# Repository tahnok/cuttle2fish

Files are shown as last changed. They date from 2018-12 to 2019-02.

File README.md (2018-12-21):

# Cuttle2Fish

Something you know (password) and something you have (cuttlefish shaped U2F token)

Based on the STM32F103

## Software

Intended to be based on https://github.com/gl-sergei/u2f-token

## Design Notes

https://github.com/tahnok/wiki/wiki/cuttle2fish

## Pictures

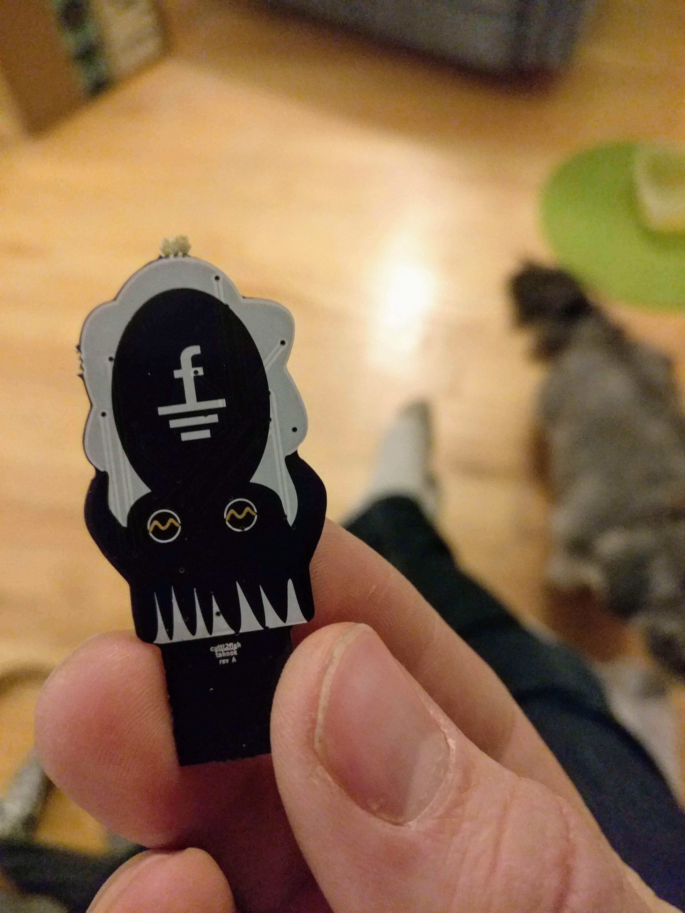
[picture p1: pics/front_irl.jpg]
front IRL


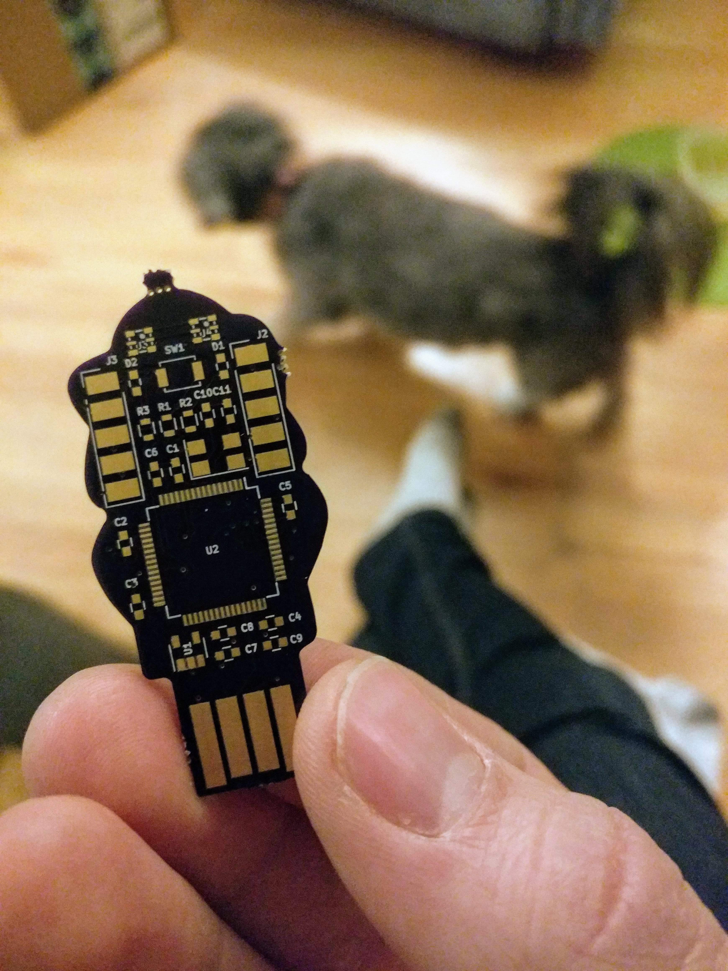
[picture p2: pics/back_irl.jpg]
back IRL


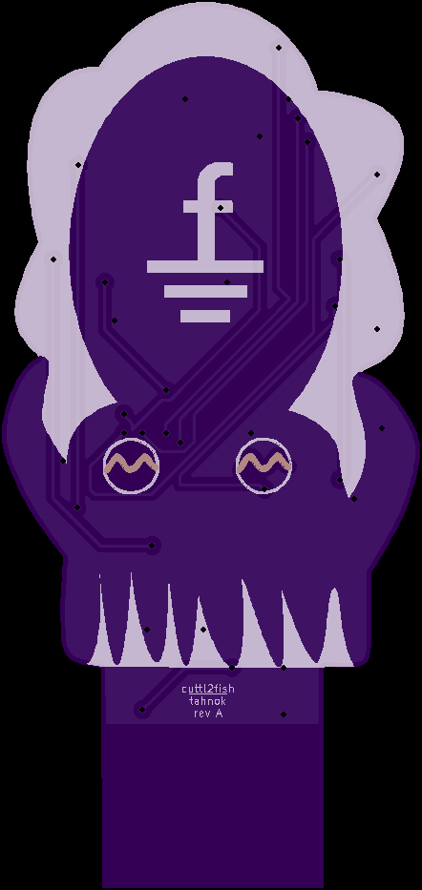
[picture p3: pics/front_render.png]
front render


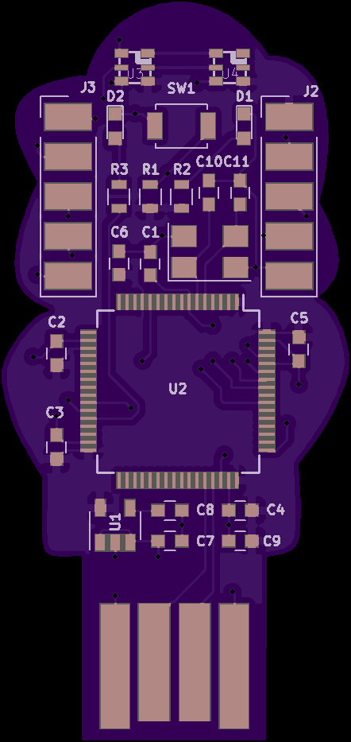
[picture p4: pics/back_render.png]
back render


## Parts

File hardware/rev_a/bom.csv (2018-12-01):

Reference | Quantity | Value | Footprint
C11 C10 | 2 | 4.7pF | SMD 0603 | https://www.digikey.ca/product-detail/en/CL10C4R7BB8NNNC/1276-1792-1-ND/3889878/?itemSeq=278517564
C6 C5 C4 C3 C2 C1 | 6 | 100nF | SMD 0603 | https://www.digikey.ca/product-detail/en/CC0603KRX7R7BB104/311-1088-1-ND/302998/?itemSeq=278517701
C8 | 1 | 10nF | SMD 0603 | https://www.digikey.ca/product-detail/en/CL10B103KB8NCNC/1276-1921-1-ND/3890007/?itemSeq=278517735
C9 C7 | 2 | 4.7uF | SMD 0603 | https://www.digikey.ca/product-detail/en/CL10A475MP5LNNC/1276-6684-1-ND/5961543/?itemSeq=278517785
D1 D2 | 2 | LED | SMD 0603 | https://www.digikey.ca/product-detail/en/SML-D12U1WT86/SML-D12U1WT86CT-ND/5843858/?itemSeq=278517839
R1 | 1 | 10K | SMD 0603 | https://www.digikey.ca/product-detail/en/ESR03EZPF1002/RHM10KADCT-ND/1983753/?itemSeq=278517879
R2 R3 | 2 | 330 | SMD 0603 | https://www.digikey.ca/product-detail/en/ESR03EZPJ331/RHM330DCT-ND/1762933/?itemSeq=278517891
SW1 | 1 | B3U-1000P | B3U-1000P | https://www.digikey.ca/product-detail/en/B3U-1000P/SW1020CT-ND/1534357/?itemSeq=278517290
U1 | 1 | LP2985-3.3 | SMD SOT-23-5 | https://www.digikey.ca/product-detail/en/LP2985-33DBVR/296-18476-1-ND/809911/?itemSeq=278517279
U2 | 1 | STM32F103R(8-B)Tx | LQFP 64 10x10mm Pitch0.5mm | https://www.digikey.ca/product-detail/en/STM32F103RBT7/497-11526-ND/2035337/?itemSeq=278517258
U3 U4 | 2 | APA102-2020 | APA102-2020 | https://www.aliexpress.com/item/-/32856952551.html
Y1 | 1 | 10pF | SMD 5032 | https://www.digikey.ca/product-detail/en/ECS-80-10-30B-CWN-TR/XC2708CT-ND/8023643/?itemSeq=278517568

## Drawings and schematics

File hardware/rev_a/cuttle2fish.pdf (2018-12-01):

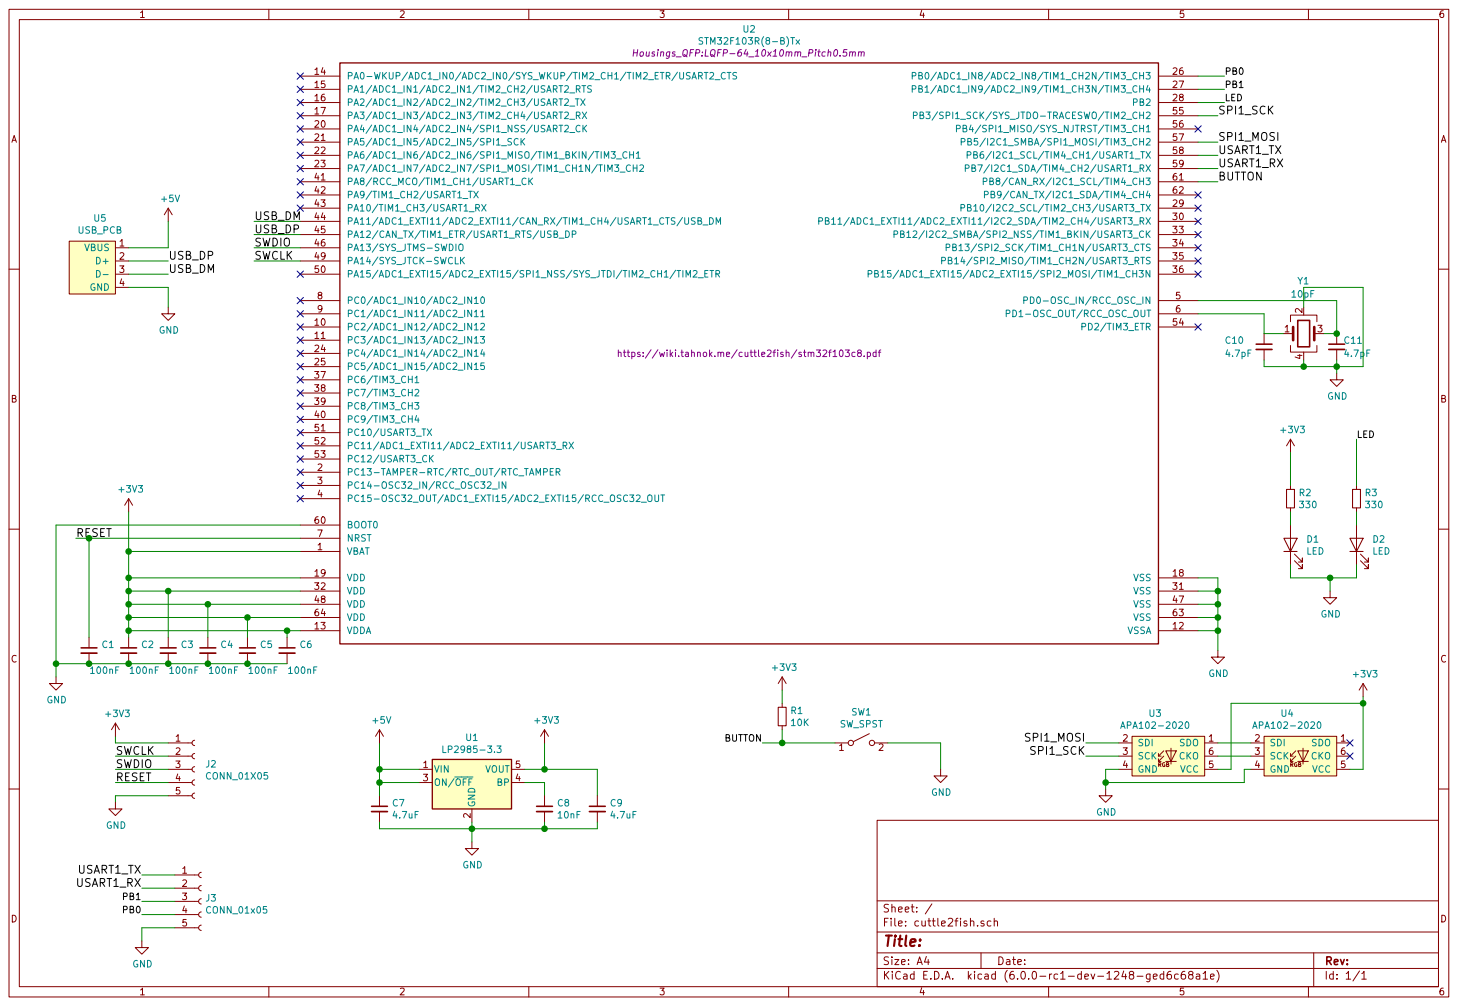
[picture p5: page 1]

2 ON/OFF 3 BP 4 VOUT 5 U1

Id: 1/1 Title: File: cuttle2fish.sch Sheet: /

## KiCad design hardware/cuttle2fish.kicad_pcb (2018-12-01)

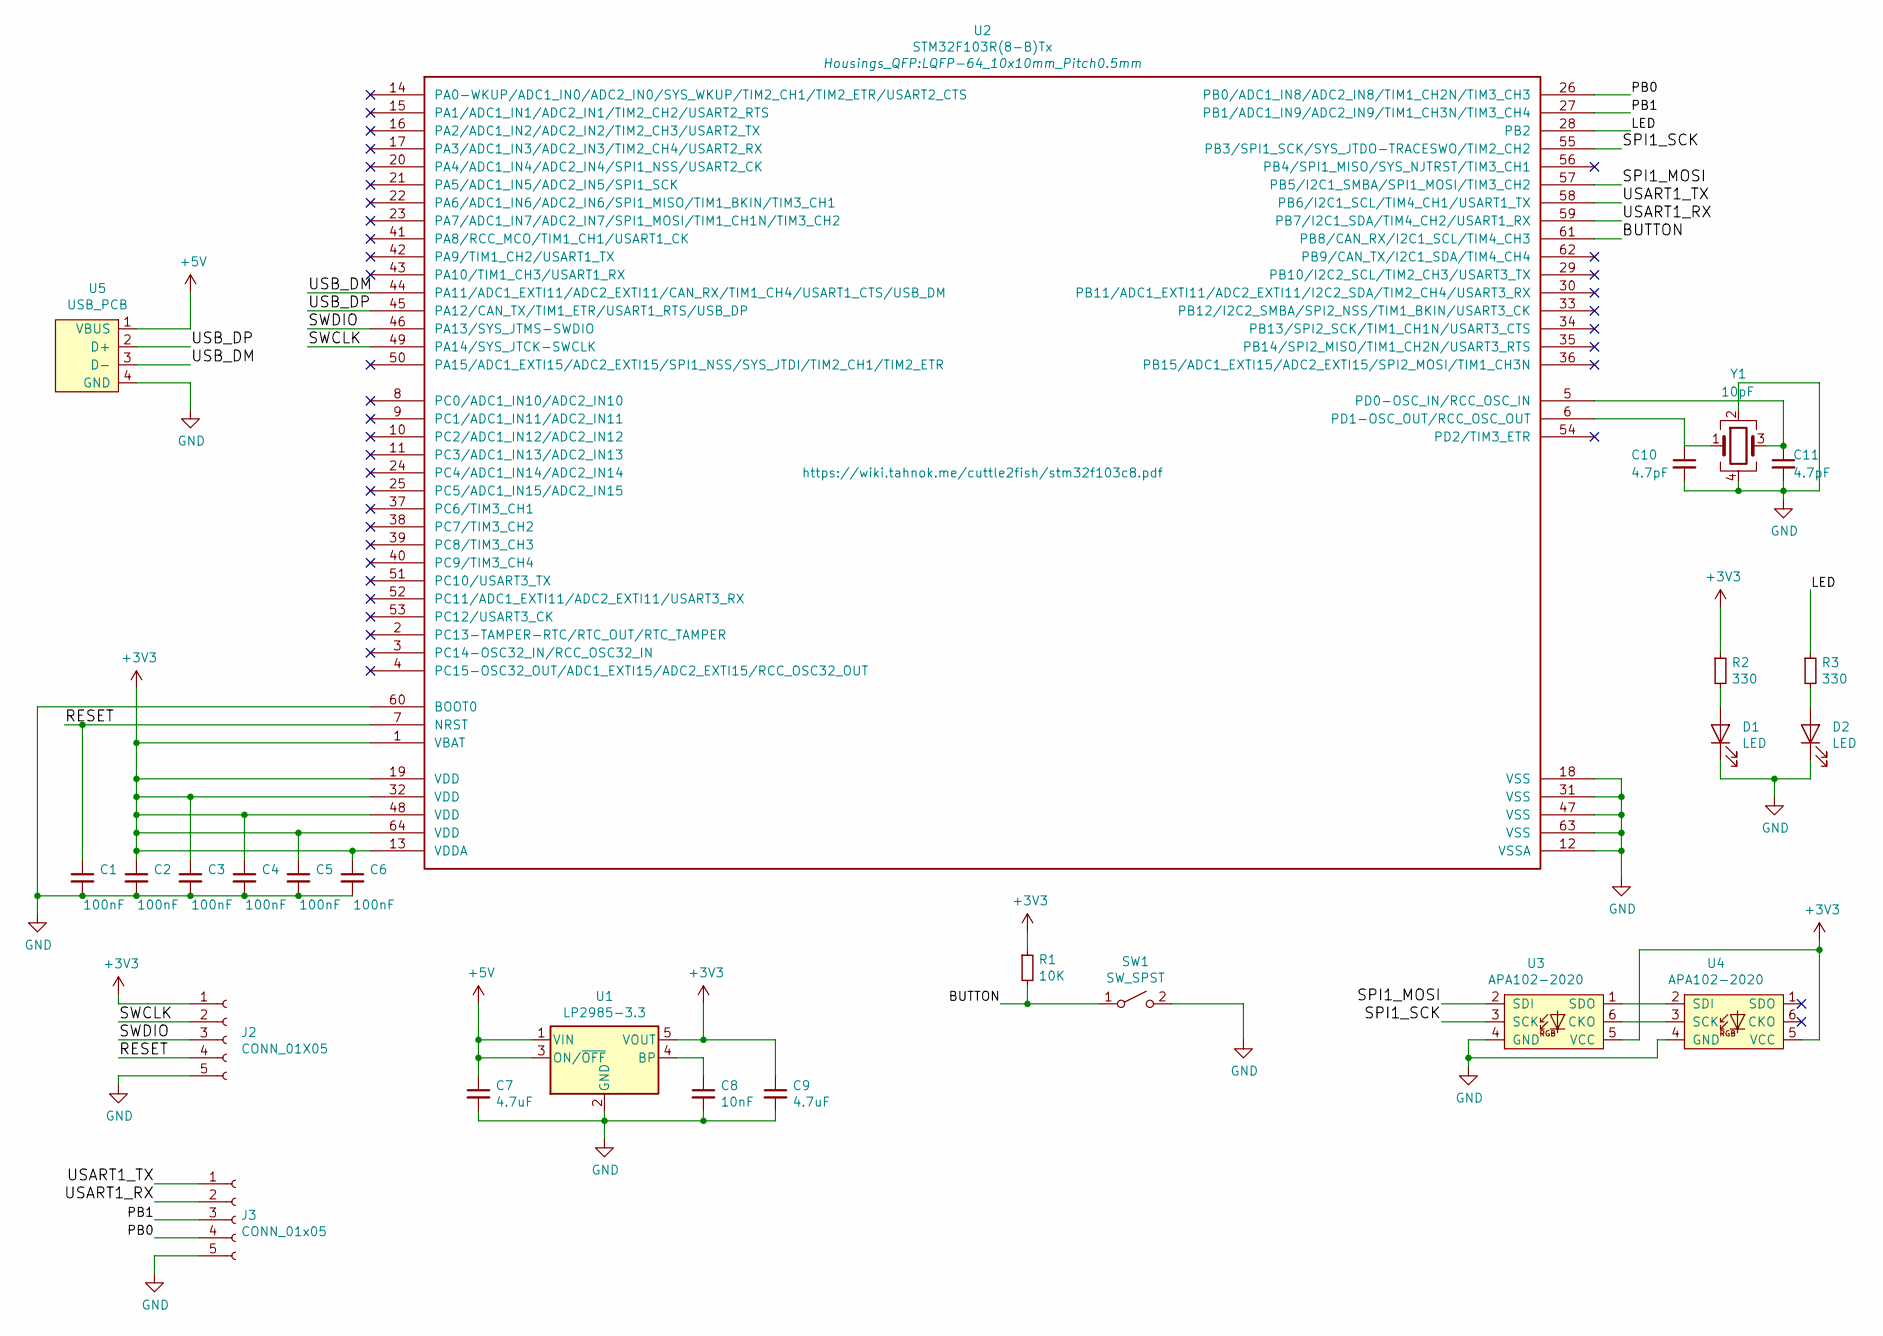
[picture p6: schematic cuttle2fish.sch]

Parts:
C1, C2, C3, C4, C5, C6: 100nF; C_0603
C7, C9: 4.7uF; C_0603
C8: 10nF; C_0603
C10, C11: 4.7pF; C_0603
D1, D2: LED; LED_0603
J2: CONN_01X05; Pin_Header_Straight_1x05_Pitch2.54mm
J3: CONN_01x05; Pin_Header_Straight_1x05_Pitch2.54mm
R1: 10K; R_0603
R2, R3: 330; R_0603
SW1: SW_SPST; SW_SPST_B3U-1000P
U1: LP2985-3.3; SOT-23-5
U2: STM32F103R(8-B)Tx; LQFP-64_10x10mm_Pitch0.5mm
U3, U4: APA102-2020
U5: USB_PCB; usb-PCB
Y1: 10pF; Crystal_SMD_5032-4pin_5.0x3.2mm

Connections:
+3V3: C2.1, C3.1, C4.1, C5.1, C6.1, C9.1, J2.1, R1.1, R2.1, U1.5 (VOUT), U2.1 (VBAT), U2.13 (VDDA), U2.19 (VDD), U2.32 (VDD), U2.48 (VDD), U2.64 (VDD), U3.5 (VCC), U4.5 (VCC)
+5V: C7.1, U1.1 (VIN), U1.3 (ON/~OFF~), U5.1 (VBUS)
/BUTTON: R1.2, SW1.1 (A), U2.61 (PB8/CAN_RX/I2C1_SCL/TIM4_CH3)
/LED: R3.1, U2.28 (PB2)
/PB0: J3.4, U2.26 (PB0/ADC1_IN8/ADC2_IN8/TIM1_CH2N/TIM3_CH3)
/PB1: J3.3, U2.27 (PB1/ADC1_IN9/ADC2_IN9/TIM1_CH3N/TIM3_CH4)
/RESET: C1.1, J2.4, U2.7 (NRST)
/SPI1_MOSI: U2.57 (PB5/I2C1_SMBA/SPI1_MOSI/TIM3_CH2), U3.2 (SDI)
/SPI1_SCK: U2.55 (PB3/SPI1_SCK/SYS_JTDO-TRACESWO/TIM2_CH2), U3.3 (SCK)
/SWCLK: J2.2, U2.49 (PA14/SYS_JTCK-SWCLK)
/SWDIO: J2.3, U2.46 (PA13/SYS_JTMS-SWDIO)
/USART1_RX: J3.2, U2.59 (PB7/I2C1_SDA/TIM4_CH2/USART1_RX)
/USART1_TX: J3.1, U2.58 (PB6/I2C1_SCL/TIM4_CH1/USART1_TX)
/USB_DM: U2.44 (PA11/ADC1_EXTI11/ADC2_EXTI11/CAN_RX/TIM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), U5.3 (D-)
/USB_DP: U2.45 (PA12/CAN_TX/TIM1_ETR/USART1_RTS/USB_DP), U5.2 (D+)
GND: C1.2, C2.2, C3.2, C4.2, C5.2, C6.2, C7.2, C8.2, C9.2, C10.2, C11.2, D1.1 (K), D2.1 (K), J2.5, J3.5, SW1.2 (B), U1.2 (GND), U2.12 (VSSA), U2.18 (VSS), U2.31 (VSS), U2.47 (VSS), U2.60 (BOOT0), U2.63 (VSS), U3.4 (GND), U4.4 (GND), U5.4 (GND), Y1.2, Y1.4
unnamed: C8.1, U1.4 (BP)
unnamed: C10.1, U2.6 (PD1-OSC_OUT/RCC_OSC_OUT), Y1.1
unnamed: C11.1, U2.5 (PD0-OSC_IN/RCC_OSC_IN), Y1.3
unnamed: D1.2 (A), R2.2
unnamed: D2.2 (A), R3.2
unnamed: U3.1 (SDO), U4.2 (SDI)
unnamed: U3.6 (CKO), U4.3 (SCK)

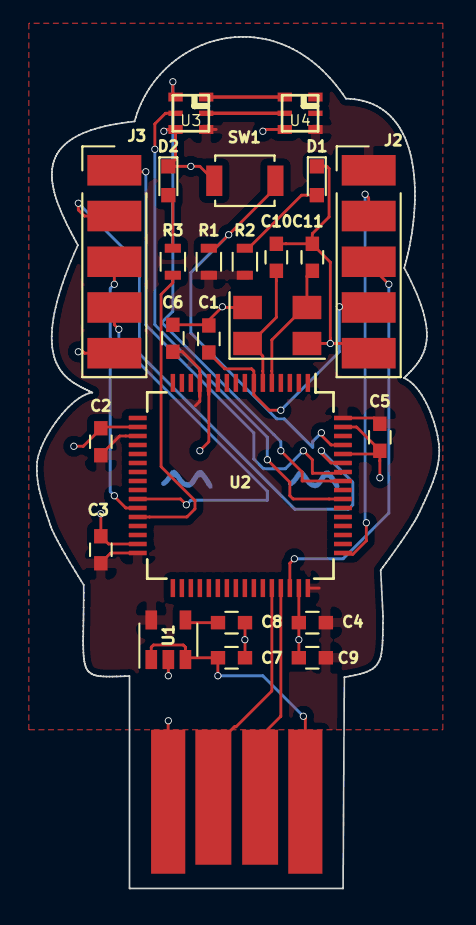
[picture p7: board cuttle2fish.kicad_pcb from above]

Board: 2 copper layers, 22.4 x 47.3 mm, 26 parts (1 on the bottom side), 23 nets.

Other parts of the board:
svg2mod: G***; outline

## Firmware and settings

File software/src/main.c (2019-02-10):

/*
 * This file is part of the libopencm3 project.
 *
 * Copyright (C) 2009 Uwe Hermann <uwe@hermann-uwe.de>
 *
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
 * You should have received a copy of the GNU Lesser General Public License
 * along with this library.  If not, see <http://www.gnu.org/licenses/>.
 */
#include <libopencm3/stm32/rcc.h>
#include <libopencm3/stm32/gpio.h>

static void
gpio_setup(void) {

	/* Enable GPIOC clock. */
	rcc_periph_clock_enable(RCC_GPIOB);

	/* Set GPIO8 (in GPIO port C) to 'output push-pull'. */
	gpio_set_mode(GPIOB,GPIO_MODE_OUTPUT_2_MHZ,
		      GPIO_CNF_OUTPUT_PUSHPULL,GPIO2);
	gpio_set_mode(GPIOB, GPIO_MODE_INPUT, GPIO_CNF_INPUT_FLOAT, GPIO6);
}

int
main(void) {
	int i;

	gpio_setup();

	uint16_t result;

	for (;;) {
		result = gpio_get(GPIOB, GPIO6);
		if(result) {
			gpio_clear(GPIOB,GPIO2);	/* LED on */
		} else {
			gpio_set(GPIOB,GPIO2);		/* LED off */
		}

	}

	return 0;
}

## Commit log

2018-11-11 Add skeleton kicad project
    [cuttle2fish.kicad_pcb, cuttle2fish.sch]
2018-11-20 add first pass at USB and power caps
    [cuttle2fish.sch]
2018-11-24 Update cuttle2fish.sch
    Add labels for pins we want to break out and programming connector
    [cuttle2fish.sch]
2018-11-25 Add APA102, button, PMIC
    [cuttle2fish.sch]
2018-11-25 Rev 1 schematic
    [cuttle2fish.sch]
2018-11-25 Add APA102 footprint from great scott gadgets
    https://github.com/greatscottgadgets/gsg-kicad-lib/blob/master/gsg-modules.pretty/APA102-2020.kicad_mod
    [cuttle2fish.sch]
2018-11-25 Add LEDs and button footprint
    [cuttle2fish.sch]
2018-11-25 Add PCB USB footprint and symbol from USBArmory
    https://github.com/inversepath/usbarmory
    [cuttle2fish.sch]
2018-11-25 rename symbol file from test to symbols
    [cuttle2fish.sch]
2018-11-30 add outline footprint and start routing!
    [cuttle2fish.kicad_pcb, cuttle2fish.sch]
2018-12-01 Update schematic with missed connections...
    [cuttle2fish.sch]
2018-12-01 routing attempt #1 (bad)
    [cuttle2fish.kicad_pcb]
2018-12-01 layout v2!
    [cuttle2fish.kicad_pcb]
2018-12-01 tweak layout, expose eyes in outline
    [cuttle2fish.kicad_pcb]
2018-12-01 rev A gerbers
    [cuttle2fish-B.Cu.gbl, cuttle2fish-B.Mask.gbs, cuttle2fish-B.SilkS.gbo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]
2018-12-01 Add bom with digikey links
    [bom.csv]
2018-12-21 stencils and readme with images
    [cuttle2fish-Edge.Cuts.gko, cuttle2fish-F.Paste.gtp]

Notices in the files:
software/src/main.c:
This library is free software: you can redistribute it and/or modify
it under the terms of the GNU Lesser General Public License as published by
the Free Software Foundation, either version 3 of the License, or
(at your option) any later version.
